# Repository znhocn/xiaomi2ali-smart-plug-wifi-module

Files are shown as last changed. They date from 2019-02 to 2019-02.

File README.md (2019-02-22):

# Xiaomi2Ali Smart Plug WiFi Module

Xiaomi Smart Plug WiFi Module to Ali 86 Smart Plug Adapter board

此项目是把从[米家智能插座基础版](https://www.mi.com/mj-socket/)里拆卸下来的 WiFi 模块转换成可供阿里智能插座-86型墙壁插座使用的模块。

使用小米的 WiFi 模块替换原有阿里智能的 WiFi 模块，实现使用米家APP控制插座，并且支持小爱同学控制。

目前米家生态链里没有直接使用 WiFi 的86型墙壁智能插座。

支持阿里86型墙壁插座的 10A 与 16A 的 WiFi 模块兼容性。

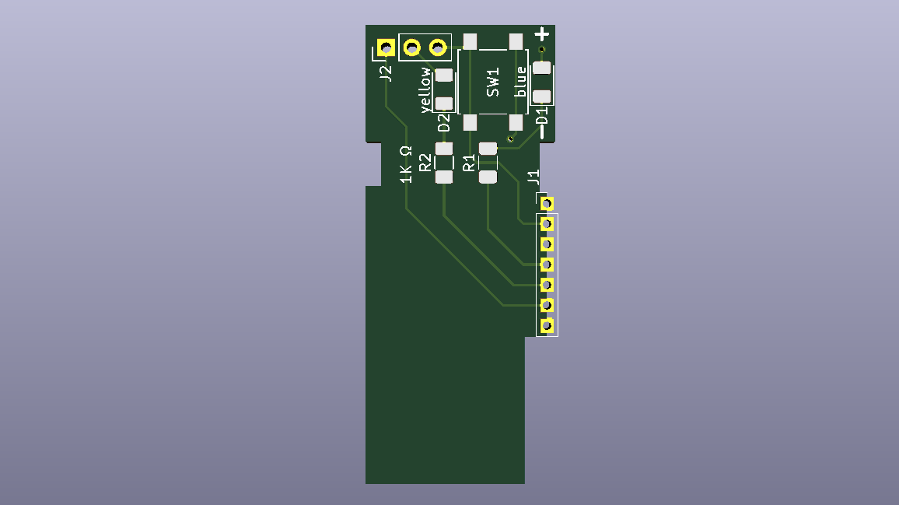
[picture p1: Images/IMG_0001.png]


发给 PCB 厂家生产时建议使用 [Rev.B](Gerber/Rev.B) 版本。

某些厂家可能不支持半孔覆铜工艺，可用 Rev.B 版本发给厂家去生产。

使用 Rev.B 生产的 PCB 需要自己在通孔焊盘上划一刀再掰开，有必要还可以用锉刀再打磨一下断裂处。

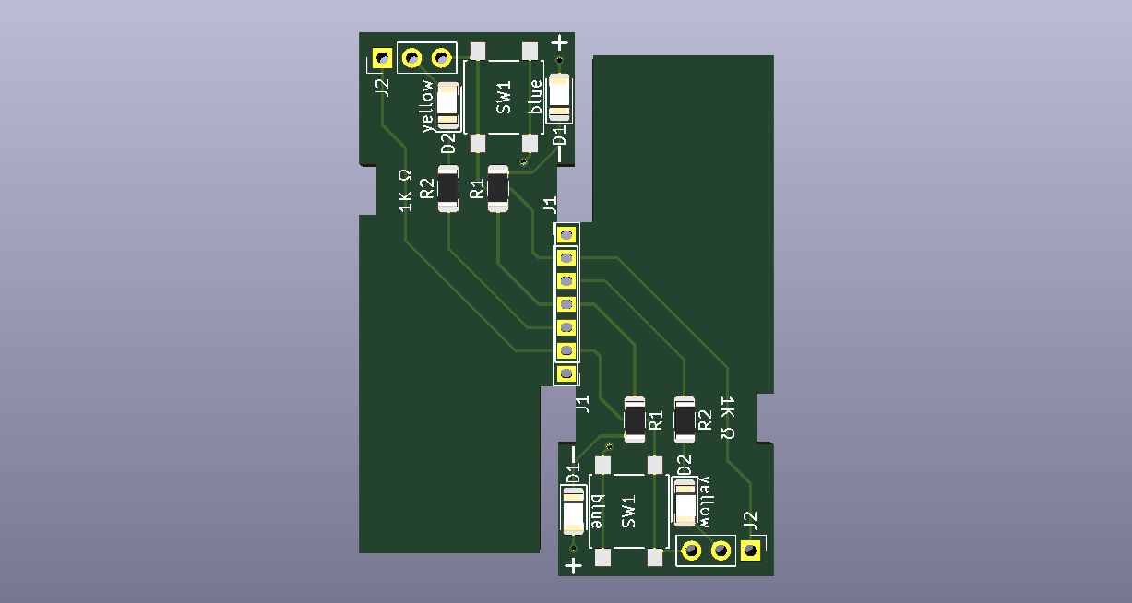
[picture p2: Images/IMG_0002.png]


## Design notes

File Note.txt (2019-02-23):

###############
#       PIN 1 #    3.3V / LED*2 +
#       PIN 2 #    GND
#       PIN 3 #    Button +
#       PIN 4 #    B_EN / LED_blue -
#       PIN 5 #    R_EN / LED_yellow -
#       PIN 6 #    Switch
#       PIN 7 #    GND
#         #####
#         #
#         #   Xiaomi Smart-Plug WiFi Module
#         #
###########

ID  PIN             黄灯(Conf)    蓝灯(On)  灭灯(Off)
1   3.3V / LEDx2 +
2   GND
3   Button +        High        High        High
4   B_EN / LED_b -  High        Low         High
5   R_EN / LED_y -  Unstable    High        High
6   Switch          High        High        Low
7   GND             

BOM
1206 LED blue       x1
1206 LED yellow     x1
1026 Resistance 1k  x2
轻触开关 6*6*3.1mm  x1

板厚: 1.6 mm

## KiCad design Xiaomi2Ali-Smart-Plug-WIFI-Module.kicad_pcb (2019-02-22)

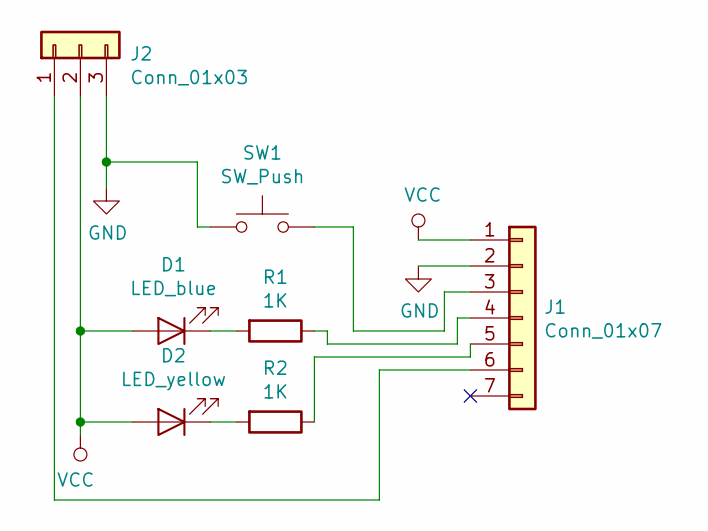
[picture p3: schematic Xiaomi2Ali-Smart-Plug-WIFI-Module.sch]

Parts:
D1: LED_blue; LED_1206_3216Metric
D2: LED_yellow; LED_1206_3216Metric
J1: Conn_01x07; PinHeader_1x07_P2.00mm_Vertical
J2: Conn_01x03; PinHeader_1x03_P2.54mm_Vertical
R1, R2: 1K; R_1206_3216Metric
SW1: SW_Push; SW_SPST_B3S-1000

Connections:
GND: J1.2, J2.3, SW1.1
unnamed: D1.1 (K), R1.2
unnamed: D2.1 (K), R2.2
unnamed: J1.3, SW1.2
unnamed: J1.4, R1.1
unnamed: J1.5, R2.1
unnamed: J1.6, J2.1
VCC: D1.2 (A), D2.2 (A), J1.1, J2.2

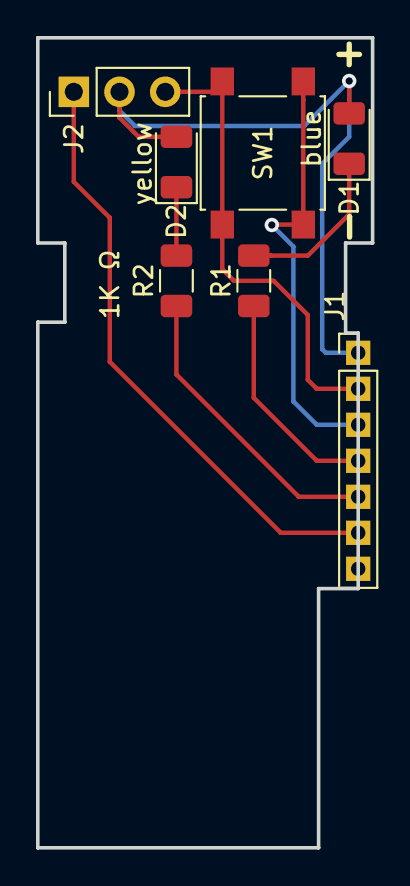
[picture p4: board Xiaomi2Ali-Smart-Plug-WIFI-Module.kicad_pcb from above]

Board: 2 copper layers, 18.6 x 45.0 mm, 7 parts (0 on the bottom side), 8 nets.

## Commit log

2019-02-17 Updated: 2019-02-17 20:07:23
    [Xiaomi2Ali-Smart-Plug-WIFI-Module-B.Cu.gbr, Xiaomi2Ali-Smart-Plug-WIFI-Module-B.Mask.gbr, Xiaomi2Ali-Smart-Plug-WIFI-Module-B.Paste.gbr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]
2019-02-17 Updated: 2019-02-18 00:24:23
    [Xiaomi2Ali-Smart-Plug-WIFI-Module-B.Cu.gbr, Xiaomi2Ali-Smart-Plug-WIFI-Module-B.Mask.gbr, Xiaomi2Ali-Smart-Plug-WIFI-Module-B.Paste.gbr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]
2019-02-17 Updated: 2019-02-18 00:42:54
    [Xiaomi2Ali-Smart-Plug-WIFI-Module-B.Cu.gbr, Xiaomi2Ali-Smart-Plug-WIFI-Module-B.Mask.gbr, Xiaomi2Ali-Smart-Plug-WIFI-Module-B.Paste.gbr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]
2019-02-18 Updated: 2019-02-18 13:14:53
    [Xiaomi2Ali-Smart-Plug-WIFI-Module-B.Cu.gbr, Xiaomi2Ali-Smart-Plug-WIFI-Module-B.Mask.gbr, Xiaomi2Ali-Smart-Plug-WIFI-Module-B.Paste.gbr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]
2019-02-18 Updated: 2019-02-18 18:36:52
    [Xiaomi2Ali-Smart-Plug-WIFI-Module-B.Cu.gbr, Xiaomi2Ali-Smart-Plug-WIFI-Module-B.Mask.gbr, Xiaomi2Ali-Smart-Plug-WIFI-Module-B.Paste.gbr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]
2019-02-19 Updated: 2019-02-20 00:25:07
    [Xiaomi2Ali-Smart-Plug-WIFI-Module-B.Cu.gbr, Xiaomi2Ali-Smart-Plug-WIFI-Module-B.Mask.gbr, Xiaomi2Ali-Smart-Plug-WIFI-Module-Edge.Cuts.gbr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]
2019-02-20 Updated: 2019-02-20 16:21:37
    [Xiaomi2Ali-Smart-Plug-WIFI-Module-B.Cu.gbr, Xiaomi2Ali-Smart-Plug-WIFI-Module-B.Mask.gbr, Xiaomi2Ali-Smart-Plug-WIFI-Module-B.Paste.gbr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]
2019-02-22 Updated: 2019-02-22 14:43:09
    [Xiaomi2Ali-Smart-Plug-WIFI-Module-B.Cu.gbr, Xiaomi2Ali-Smart-Plug-WIFI-Module-B.Mask.gbr, Xiaomi2Ali-Smart-Plug-WIFI-Module-B.Paste.gbr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]
